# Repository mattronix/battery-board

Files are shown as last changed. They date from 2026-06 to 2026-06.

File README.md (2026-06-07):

# PRC‑152A Repro — Battery / Radio Interface Boards

KiCad hardware project for the **battery-to-radio interface** of an AN/PRC‑152(A)
reproduction radio. It contains two small PCBs that mate through spring‑loaded
**pogo‑pin contacts**, plus a shared custom KiCad **footprint library** for those
mechanical contacts.

> All boards are designed in **KiCad 10** and built for fabrication/assembly at
> JLCPCB (Fabrication Toolkit export, JLCPCB BOM).

---

## Repository layout

```
battery-board/
├── Battery Top/                      # Board that sits on the battery
│   ├── Battery Top/                  # KiCad project (.kicad_pro/.kicad_sch/.kicad_pcb)
│   │   └── production/               # Gerbers/BOM/positions for JLCPCB
│   └── BOM/                          # JLCPCB BOM spreadsheet
├── Radio Bottom/                     # Board that sits on the radio body
│   └── Battery Bottom/               # KiCad project (folder name differs from board name)
├── Kicad Footprint Libaries/
│   └── Radio Library.pretty/         # ← the shared custom footprint library
└── README.md
```

> Note: a couple of folder names are inconsistent with the board names
> (`Radio Bottom/Battery Bottom/...`). The board you load is the `.kicad_pro`
> inside each, not the folder name.

---

## The two boards

### Battery Top
The interface board on the **battery** side. Carries power up to the radio and
exposes the data line.

| Ref | Part | Footprint | Purpose |
|-----|---|---|---|
| J1 | JST XH 3‑pin vertical | `Connector_JST:...B3B-XH-A` | Battery power/data harness |
| J2, J3 | Pogo pin | `Radio Library:Pogo Battery 7MM` | VBAT+ contacts to radio |
| J5 | Pogo pin | `Radio Library:Pogo Battery 7MM` | DATA contact to radio |
| J4, J6 | Bolt pad | `Radio Library:Bolt Pad 4.25` | GND / M4 mounting bolt |
| F1 | 1206 fuse | `Fuse:Fuse_1206_3216Metric` | VBAT+ protection |

### Radio Bottom
The interface board on the **radio** side. It does battery current/power
monitoring and switches the load.

| Ref | Part | Footprint | Purpose |
|-----|---|---|---|
| U1 | **INA226** power monitor | `Package_SO:MSOP-10_3x3mm` | I²C voltage/current/power sense |
| R1 | 5 mΩ shunt | `Resistor_SMD:R_2512_6332Metric` | Current‑sense resistor for U1 |
| Q1 | AOD403 / FQP27P06 P‑MOSFET | `Package_TO_SOT_SMD:TO-252-2` | Load switch / reverse protection |
| D1 | Zener | `Diode_SMD:D_SOD-123` | Gate / rail clamp |
| C1 | 0.1 µF 0603 | `Capacitor_SMD:C_0603` | Decoupling |
| R4 | 100 kΩ 0603 | `Resistor_SMD:R_0603` | Bias/pull |
| J1 | JST XH 6‑pin vertical | `Connector_JST:...B6B-XH-A` | Harness to radio |
| J2,J3 | Pogo pin | `Radio Library:Pogo Radio Bottom 6MM` | Power/data contacts from battery |
| J4,J6 | Bolt pad | `Radio Library:Bolt Pad 4.25` | GND / mounting bolt |

The two boards face each other: the **Pogo Battery 7MM** contacts on *Battery Top*
press onto the **Pogo Radio Bottom 6MM** contacts on *Radio Bottom*, carrying
VBAT+, GND and DATA across the mechanical joint. The INA226 + 5 mΩ shunt measure
battery current/voltage and report over the data line.

---

## Additional parts required (beyond the BOMs)

The electronic BOM spreadsheets (`*/BOM/*.xls`) cover the parts placed by JLCPCB.
You also need the following mechanical / assembly parts to build a working unit:

| Part | Spec / Source | Used on |
|---|---|---|
| Battery | 1× — [AliExpress](https://www.aliexpress.com/item/1005009778488275.html) | Battery Top |
| O‑ring | 13.9 × 1.8 mm | Assembly seal |
| Stainless‑steel printed part | Metal (stainless) 3D print | Mechanical |
| Battery tabs | — | Battery Top |
| Pogo pin — Radio side, 6 mm height | [AliExpress](https://www.aliexpress.com/item/1005006095992803.html) | Radio Bottom (`Pogo Radio Bottom 6MM`) |
| Pogo pin — Battery side, 7 mm height | [AliExpress](https://www.aliexpress.com/item/32862727404.html) | Battery Top (`Pogo Battery 7MM`) |

---

## The custom footprint library (`Radio Library`)

`Kicad Footprint Libaries/Radio Library.pretty/` is a standard KiCad `.pretty`
footprint library — a folder of `.kicad_mod` files, one per footprint. It holds
the **non‑standard mechanical contacts** that aren't in KiCad's stock libraries.

| Footprint | Pad | Drill | Pad Ø | Used for |
|---|-----|---|---|---|
| **Pogo Battery 7MM** | 1× THT circle | 1.6 mm | 2.5 mm | Pogo pin pressed from the battery side |
| **Pogo Radio Bottom 6MM** | 1× THT circle | 0.9 mm | 2.5 mm | Mating pogo target on the radio side |
| **Bolt Pad 4.25** | 1× THT circle | 4.3 mm | 7 mm | M4 mounting bolt + GND pad |

Each is a single through‑hole pad — these are mechanical/contact features rather
than multi‑pin parts, so the drill size is chosen to fit the specific pogo pin or
bolt.

> `*.kicad_mod.rsls` and `Untitled*` files in the library folder are editor
> scratch/temp artifacts and are not real footprints.

### How the boards find the library

Each project's `fp-lib-table` registers the library under the nickname
**`Radio Library`** via an **absolute path**:

```
(lib (name "Radio Library") (type "KiCad")
     (uri "/Users/.../PCB Design/Kicad Footprint Libaries/Radio Library.pretty"))
```

Footprints are then referenced as `Radio Library:<name>` (e.g.
`Radio Library:Pogo Battery 7MM`) in the PCBs.

⚠️ **The path is hard‑coded and absolute.** On another machine (or if you move the
repo) KiCad won't find the library and the custom footprints will show as
unresolved. Fix it one of two ways:

1. **Per project** — open *Preferences → Manage Footprint Libraries → Project*
   and re‑point the `Radio Library` row at this repo's
   `Kicad Footprint Libaries/Radio Library.pretty`, **or**
2. **Use a path variable** — define `KIPRJMOD`‑relative or a custom
   `${RADIO_LIB}` environment variable and edit each `fp-lib-table` to use it,
   so the project is portable.

---

## Working with the project

### Open in KiCad
Open the `.kicad_pro` inside `Battery Top/Battery Top/` or
`Radio Bottom/Battery Bottom/`. If footprints are unresolved, fix the
`Radio Library` path as described above.

### Re‑generate fabrication output
Each project has a `production/` folder (gerbers zip, `bom.csv`,
`positions.csv`, `designators.csv`) produced by the **Fabrication Toolkit**
plugin (settings in `fabrication-toolkit-options.json`). Re‑run the plugin after
PCB changes to refresh these, then upload the zip + BOM to JLCPCB.

---

## Contributing

Improvements are welcome. Open an issue for anything non‑trivial, keep pull
requests focused on one change, and re‑export the `production/` output if you
touch a PCB. See [`CONTRIBUTING.md`](CONTRIBUTING.md) for the full workflow and
guidelines.

## License

This project is licensed under the **CERN Open Hardware Licence Version 2 –
Weakly Reciprocal (CERN‑OHL‑W v2)** — see [`LICENSE`](LICENSE).

You are free to use, study, modify, share and manufacture these designs. Because
the licence is *weakly reciprocal*, if you **distribute modified versions** of
these boards you must make your modified design (source) files **available under
the same licence**. The boards may be incorporated into a larger product without
that product as a whole having to be open.

`SPDX-License-Identifier: CERN-OHL-W-2.0`

## Notes

- `.gitignore` only excludes `.DS_Store`. KiCad lock files (`~*.lck`), `.history/`
  editor backups, and `production/` outputs are currently committed — consider
  ignoring the first two.
- Footprint files carry KiCad 10 (`version 20260206`, `generator_version 10.0`);
  open with KiCad 10 or newer to avoid format warnings.

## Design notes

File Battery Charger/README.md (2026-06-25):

# Battery Charger

Off‑the‑shelf charger used to charge the battery pack for the PRC‑152A
reproduction. This is **not a board designed in this repo** — it is a purchased
module. The `Fusion/` folder holds the mechanical model for fitting/mounting it.

## BOM

| Part | Spec | Source |
|---|---|---|
| Lithium battery charger module | **3S, 2 A** | [AliExpress](https://nl.aliexpress.com/item/1005006823992898.html) — select the **3S 2 A** variant |

> ⚠️ Order the **3S 2 A** variant specifically. The listing offers multiple
> cell‑count (S) and current (A) options; only the 3S 2 A part matches this pack.

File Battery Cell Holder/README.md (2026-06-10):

# Battery Cell Holder

The cell pack of the PRC‑152A reproduction. Two stacked PCBs sandwich the
cylindrical cells: one board carries the spring contacts at each cell end, and
the pack feeds the *Battery Top* interface board. The custom **spring‑contact**
footprint library used by both boards lives here too.

## Layout

```
Battery Cell Holder/
├── Battery Cell Holder Top PCB/
│   └── Kicad/                 # KiCad 10 project — open Battery Cell Holder Top PCB.kicad_pro
├── Battery Cell Holder Bottom PCB/
│   └── Kicad/                 # KiCad 10 project — open Battery Cell Bottom PCB.kicad_pro
└── BatterySpringContact-kicad/   # shared custom symbol + footprint library (see its own README)
```

> Note: the bottom board's project file is named `Battery Cell Bottom PCB.*`
> while its folder is `Battery Cell Holder Bottom PCB/` — open the `.kicad_pro`,
> not the folder name.

## The two boards

Each board carries six battery spring contacts (`BT1`–`BT6`) plus solder‑wire
test points (`TP1`–`TP4`). The top and bottom boards face the opposite ends of
the cells so the springs press axially onto the cell terminals.

| Ref | Part | Footprint | Purpose |
|-----|---|---|---|
| BT1–BT6 | Battery spring contact | `BatterySpringContact:Keystone_5222_SpringContact_THM` | Per‑cell end contacts |
| BT | Battery spring contact (plate) | `BatterySpringContact:BatteryContact_uxcell_Plate_TabSolder_18650` | Plate‑style contact variant |
| TP1–TP4 | Test point | `Connector_Wire:SolderWire-1.5sqmm_1x01_D1.7mm_OD3.9mm` | Wire solder / probe points |

These are generic mechanical contacts with **no LCSC part number**, so JLCPCB's
pick‑and‑place can't assemble them — the board is fabricated with the correct
land and you **hand‑solder** the contacts afterward.

## Footprint library

`BatterySpringContact-kicad/` is a standard KiCad symbol + `.pretty` footprint
library for the stamped 18650/AA spring contacts (coil‑spring negative end,
conical‑button positive end, plus a 7 mm conical PCB spring). It carries its own
detailed README — including footprint dimensions to measure, mounting notes, and
the 3D‑model setup. **Read [`BatterySpringContact-kicad/README.md`](BatterySpringContact-kicad/README.md) before editing the footprints.**

⚠️ The 7 mm conical PCB spring uses 0.3 mm wire — low current capacity. Fine for
sense/monitor paths; do **not** route high pack‑discharge current through it.

## Working with it

1. Open the `.kicad_pro` in **KiCad 10** or newer (one project per board).
2. If the `Battery_Spring_Contact` symbol or its footprints show as unresolved,
   register the `BatterySpringContact` symbol/footprint libraries under that
   nickname — see [`BatterySpringContact-kicad/README.md`](BatterySpringContact-kicad/README.md).
3. The footprint references the STEP model via `${KIPRJMOD}`, so copy the
   `.step`/`.wrl` next to the `.kicad_pcb` (or re‑point the 3D‑model path) for
   the 3D viewer.

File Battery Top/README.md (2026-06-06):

# Battery Top

Interface board on the **battery** side of the PRC‑152A reproduction. It carries
power up from the battery to the radio and exposes the data line, mating to
*Radio Bottom* through spring‑loaded pogo‑pin contacts.

## Layout

```
Battery Top/
├── Kicad/                 # KiCad 10 project — open Battery Top.kicad_pro here
│   ├── Battery Top.kicad_pro / .kicad_sch / .kicad_pcb / .kicad_dru
│   ├── fp-lib-table       # registers the shared "Radio Library" footprint lib
│   ├── fabrication-toolkit-options.json
│   └── production/        # JLCPCB output (gerbers zip, BOM, positions) — git-ignored
└── BOM/
    └── JLPCB BOM v1.xls   # JLCPCB BOM spreadsheet
```

## Key components

| Ref | Part | Footprint | Purpose |
|-----|---|---|---|
| J1 | JST XH 3‑pin vertical | `Connector_JST:...B3B-XH-A` | Battery power/data harness |
| J2, J3 | Pogo pin | `Radio Library:Pogo Battery 7MM` | VBAT+ contacts to radio |
| J5 | Pogo pin | `Radio Library:Pogo Battery 7MM` | DATA contact to radio |
| J4, J6 | Bolt pad | `Radio Library:Bolt Pad 4.25` | GND / M4 mounting bolt |
| F1 | 1206 fuse | `Fuse:Fuse_1206_3216Metric` | VBAT+ protection |

The **Pogo Battery 7MM** contacts here press onto the **Pogo Radio Bottom 6MM**
targets on *Radio Bottom*, carrying VBAT+, GND and DATA across the joint.

## Working with it

1. Open `Kicad/Battery Top.kicad_pro` in **KiCad 10** or newer.
2. If the custom pogo/bolt footprints show as unresolved, re‑point the
   `Radio Library` entry — see [`../Kicad Footprint Libaries/README.md`](../Kicad%20Footprint%20Libaries/README.md).
3. After PCB changes, re‑run the **Fabrication Toolkit** plugin to refresh
   `production/`, then upload the zip + BOM to JLCPCB.

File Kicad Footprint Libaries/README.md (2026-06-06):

# Kicad Footprint Libaries

Shared custom KiCad footprint library for the PRC‑152A interface boards. Both
*Battery Top* and *Radio Bottom* reference it under the nickname **`Radio Library`**.

## Layout

```
Kicad Footprint Libaries/
└── Radio Library.pretty/   # standard KiCad .pretty library (one .kicad_mod per footprint)
```

A `.pretty` folder is just a directory of `.kicad_mod` files — KiCad treats the
folder itself as one library.

## Footprints

These are the **non‑standard mechanical contacts** that aren't in KiCad's stock
libraries. Each is a single through‑hole pad — a mechanical/contact feature, not
a multi‑pin part — sized to fit a specific pogo pin or bolt.

| Footprint | Pad | Drill | Pad Ø | Used for |
|---|-----|---|---|---|
| **Pogo Battery 7MM** | 1× THT circle | 1.6 mm | 2.5 mm | Pogo pin pressed from the battery side |
| **Pogo Radio Bottom 6MM** | 1× THT circle | 0.9 mm | 2.5 mm | Mating pogo target on the radio side |
| **Bolt Pad 4.25** | 1× THT circle | 4.3 mm | 7 mm | M4 mounting bolt + GND pad |

> `*.kicad_mod.rsls` and `Untitled*` files are editor scratch/temp artifacts, not
> real footprints (they are git‑ignored).

## How projects find the library

Each project's `fp-lib-table` registers this library under the nickname
**`Radio Library`** via an **absolute path**:

```
(lib (name "Radio Library") (type "KiCad")
     (uri "/Users/.../Kicad Footprint Libaries/Radio Library.pretty"))
```

Footprints are then referenced as `Radio Library:<name>` (e.g.
`Radio Library:Pogo Battery 7MM`) in the PCBs.

⚠️ **The path is hard‑coded and absolute.** On another machine — or if the repo
moves — KiCad won't find the library and the custom footprints show as unresolved.
Fix it one of two ways:

1. **Per project** — *Preferences → Manage Footprint Libraries → Project* and
   re‑point the `Radio Library` row at this repo's `Radio Library.pretty`, **or**
2. **Use a path variable** — define a custom `${RADIO_LIB}` environment variable
   and edit each `fp-lib-table` to use it, so the projects stay portable.

Footprints carry the KiCad 10 format (`version 20260206`, `generator_version 10.0`);
open with KiCad 10 or newer to avoid format warnings.

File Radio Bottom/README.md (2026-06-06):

# Radio Bottom

Interface board on the **radio** side of the PRC‑152A reproduction. It does
battery voltage/current/power monitoring (INA226 + shunt) and switches the load,
mating to *Battery Top* through spring‑loaded pogo‑pin contacts.

## Layout

```
Radio Bottom/
├── Kicad/                  # KiCad 10 project — open Radio Bottom.kicad_pro here
│   ├── Radio Bottom.kicad_pro / .kicad_sch / .kicad_pcb / .kicad_dru
│   ├── fp-lib-table        # registers the shared "Radio Library" footprint lib
│   └── fabrication-toolkit-options.json
└── BOM/
    └── Radio Bottom BOM V1.xls   # JLCPCB BOM spreadsheet
```

## Key components

| Ref | Part | Footprint | Purpose |
|-----|---|---|---|
| U1 | **INA226** power monitor | `Package_SO:MSOP-10_3x3mm` | I²C voltage/current/power sense |
| R1 | 5 mΩ shunt | `Resistor_SMD:R_2512_6332Metric` | Current‑sense resistor for U1 |
| Q1 | AOD403 / FQP27P06 P‑MOSFET | `Package_TO_SOT_SMD:TO-252-2` | Load switch / reverse protection |
| D1 | Zener | `Diode_SMD:D_SOD-123` | Gate / rail clamp |
| C1 | 0.1 µF 0603 | `Capacitor_SMD:C_0603` | Decoupling |
| R4 | 100 kΩ 0603 | `Resistor_SMD:R_0603` | Bias/pull |
| J1 | JST XH 6‑pin vertical | `Connector_JST:...B6B-XH-A` | Harness to radio |
| J2, J3 | Pogo pin | `Radio Library:Pogo Radio Bottom 6MM` | Power/data contacts from battery |
| J4, J6 | Bolt pad | `Radio Library:Bolt Pad 4.25` | GND / mounting bolt |

The **Pogo Radio Bottom 6MM** targets here receive the **Pogo Battery 7MM**
contacts from *Battery Top*. The INA226 + 5 mΩ shunt measure battery
current/voltage and report over the data line.

## Working with it

1. Open `Kicad/Radio Bottom.kicad_pro` in **KiCad 10** or newer.
2. If the custom pogo/bolt footprints show as unresolved, re‑point the
   `Radio Library` entry — see [`../Kicad Footprint Libaries/README.md`](../Kicad%20Footprint%20Libaries/README.md).
3. After PCB changes, re‑run the **Fabrication Toolkit** plugin to refresh the
   fabrication output, then upload the zip + BOM to JLCPCB.

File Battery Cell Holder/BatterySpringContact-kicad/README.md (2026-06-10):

# Battery Contact — KiCad library (uxcell plate-style spring/button)

KiCad symbol + footprints for the uxcell-style stamped 18650/AA battery contact set
(flat plate, solder tab with end hole; coil spring = negative end, conical button =
positive end). One footprint serves BOTH ends — they mount identically; only the
cell-side feature differs.

## Contents
- `BatterySpringContact.kicad_sym` — symbol `Battery_Spring_Contact` (1 pin, passive)
- `BatterySpringContact.pretty/`
  - `BatteryContact_uxcell_Plate_TabSolder_18650.kicad_mod`  ← use this for your part
  - `Keystone_5222_SpringContact_THM.kicad_mod`              ← coil-spring alt (legacy)

## JLCPCB reality (read this)
This is a generic mechanical contact with NO LCSC part number, so JLCPCB's pick-and-place
CANNOT assemble it. JLCPCB will fabricate the board with the correct land; you HAND-SOLDER
the contacts afterward. Want JLCPCB to actually place a spring during assembly? You must
switch to an LCSC-catalogued SMD battery clip instead.

## How the footprint mounts
- Lay the metal tab FLAT onto the SMD pad and solder it (iron or paste+hotplate).
- The plated through-hole at the tab end is a solder/wire anchor.
- The plate + spring/button stands UP off the board toward the cell.
- Both the pad and the hole are tied to net "1" (single contact = one node).

## Footprint dimensions — NOMINAL, MEASURE TO CONFIRM
Built for the ~16 mm 18650 plate variant. Check these 5 numbers with calipers and edit
the `.kicad_mod` (values in mm):
1. Plate width (across) — sets fab/silk/courtyard circle. Nominal 16 (radius 8).
2. Tab length — sets SMD pad X (`size 9 6`) and pad center (`at 10.5 0`). Nominal ~9.
3. Tab width — sets SMD pad Y. Nominal 6.
4. Tab-end hole diameter — sets drill (`drill 1.8`). Nominal 1.8.
5. Plate-edge → hole-center distance — sets PTH `at 13 0`. Nominal 13.

Common size families if unsure: AA ≈ 12–13 mm plate; 18650 ≈ 16×16 or 18.5×16 mm.

## Install (KiCad 8)
1. Symbol: Preferences → Manage Symbol Libraries → add `BatterySpringContact.kicad_sym`
   (nickname `BatterySpringContact`).
2. Footprint: Preferences → Manage Footprint Libraries → add the `BatterySpringContact.pretty`
   folder under the SAME nickname so the symbol's default-footprint link resolves.
3. Place `Battery_Spring_Contact` once per cell end; assign +/− nets as needed.

## Mechanical (your 3D-printed shell)
- Capture the plate in the printed shell; don't rely on the solder joint for retention,
  especially under recoil/vibration (milsim use).
- Size the shell around the spring's COMPRESSED height so flat-top and protected cells
  both seat under contact pressure.

## RECOMMENDED footprint: BatterySpringContact_ConicalPCB_7mm
Conical PCB coil-spring contact (the 7 mm one). Verified dimensions:
- base coil OD 7 mm  -> 7.5 mm circular solder pad
- top coil OD 5 mm   -> what the cell end presses on
- free height 7 mm, wire 0.3 mm
Mount: solder base coil flat to the round pad; cell compresses the top axially.
This is the symbol's default footprint now.
WARNING: 0.3 mm wire is thin -> low current capacity. Great for sense/monitor or
low-current paths; do NOT route high pack-discharge current through it. Hand-solder
with flux (nickel-plated steel wets poorly); NOT JLCPCB pick-and-place.

## 3D model (STEP + WRL)
Files `BatterySpringContact_ConicalPCB_7mm.step` (66 KB, true mm) and `.wrl` (render).
The footprint already references the STEP via:
  (model "${KIPRJMOD}/BatterySpringContact_ConicalPCB_7mm.step" ...)
So the SIMPLEST setup: copy the .step (and .wrl) file into your KiCad PROJECT folder
(next to your .kicad_pcb) and ${KIPRJMOD} resolves automatically.

If you keep the models inside the .pretty folder instead, re-point the path:
  PCB editor -> double-click the footprint -> 3D Models tab -> remove the entry ->
  Add -> browse to the .step file. KiCad writes the correct absolute path for you.

Model is authored base-at-origin, +Z up (sits on top copper, spring points at the cell),
so offset/rotate are zero and scale is 1. KiCad 8's 3D viewer renders STEP directly.

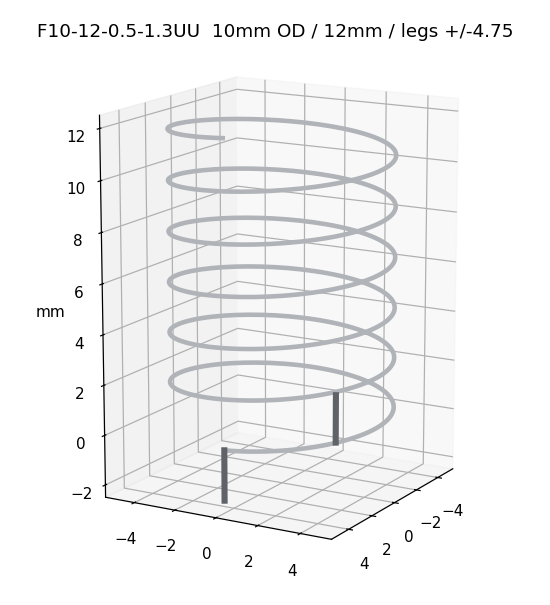
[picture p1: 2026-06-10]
Battery Cell Holder/BatterySpringContact-kicad/files/f10_preview.png

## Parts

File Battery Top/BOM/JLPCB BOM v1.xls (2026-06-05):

Comment | Designator | Footprint | JLCPCB Part # | Qty | Ext.Price($)
FUSE_VBAT+_1 | F1 | 1206 | C883162 | 14 | 1.19
JST_PWR_CON | J1 | JST_XH_B3B-XH-A_1x03_P2.50mm_Vertical | C144394 | 11 | 0.60

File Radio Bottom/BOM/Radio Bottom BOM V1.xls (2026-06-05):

Comment | Designator | Footprint | JLCPCB Part # | Qty | Ext.Price($)
5mΩ | R1 | 2512 | C46634460 | 7 | 0.46
Conn_01x06_Pin | J1 | JST_XH_B6B-XH-A_1x06_P2.50mm_Vertical | C144397 | 5 | 0.44
D_Zener | D1 | D_SOD-123 | C43491 | 15 | 0.28
INA226 | U1 | MSOP-10_3x3mm_P0.5mm | C49851 | 5 | 4.05
100K | R4 | 0603 | C25803 | 5 | 0.01
AOD403 | Q1 | TO_SOT_SMD:TO-252-2 | C5224305 | 5 | 0.77
0.1μF | C1 | 0603 | C1590 | 20 | 0.10

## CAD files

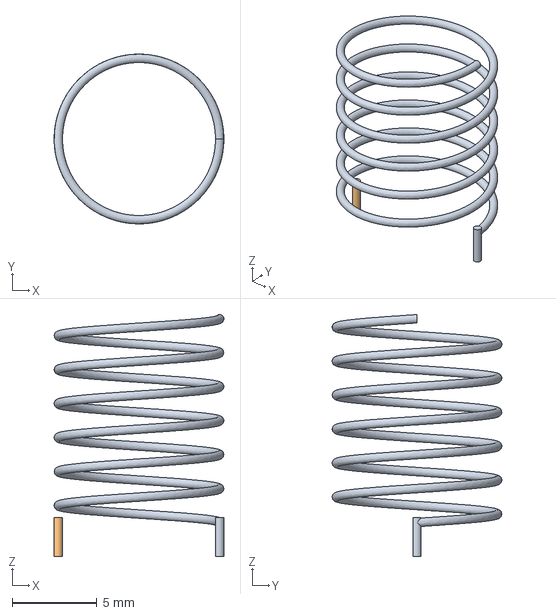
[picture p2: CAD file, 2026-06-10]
Battery Cell Holder/BatterySpringContact-kicad/files/C19724688_F10-12-0.5-1.3UU.step
10.0 x 10.00 x 14.2 mm

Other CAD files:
Battery Cell Holder/Battery Cell Holder Bottom PCB/Fusion/18650 Holder Bottom (Cell Holder PCB).f3z
Battery Cell Holder/Battery Cell Holder Spacer/Fusion/18650 Cell Holder Spacer.f3d
Battery Cell Holder/Battery Cell Holder Top PCB/Fusion/18650 Holder Top (Cell Holder + PCB).f3z
Battery Charger/Fusion/Charger.f3d
Radio Bottom/Fusion/Radio Bottom PCB Compatible.f3d

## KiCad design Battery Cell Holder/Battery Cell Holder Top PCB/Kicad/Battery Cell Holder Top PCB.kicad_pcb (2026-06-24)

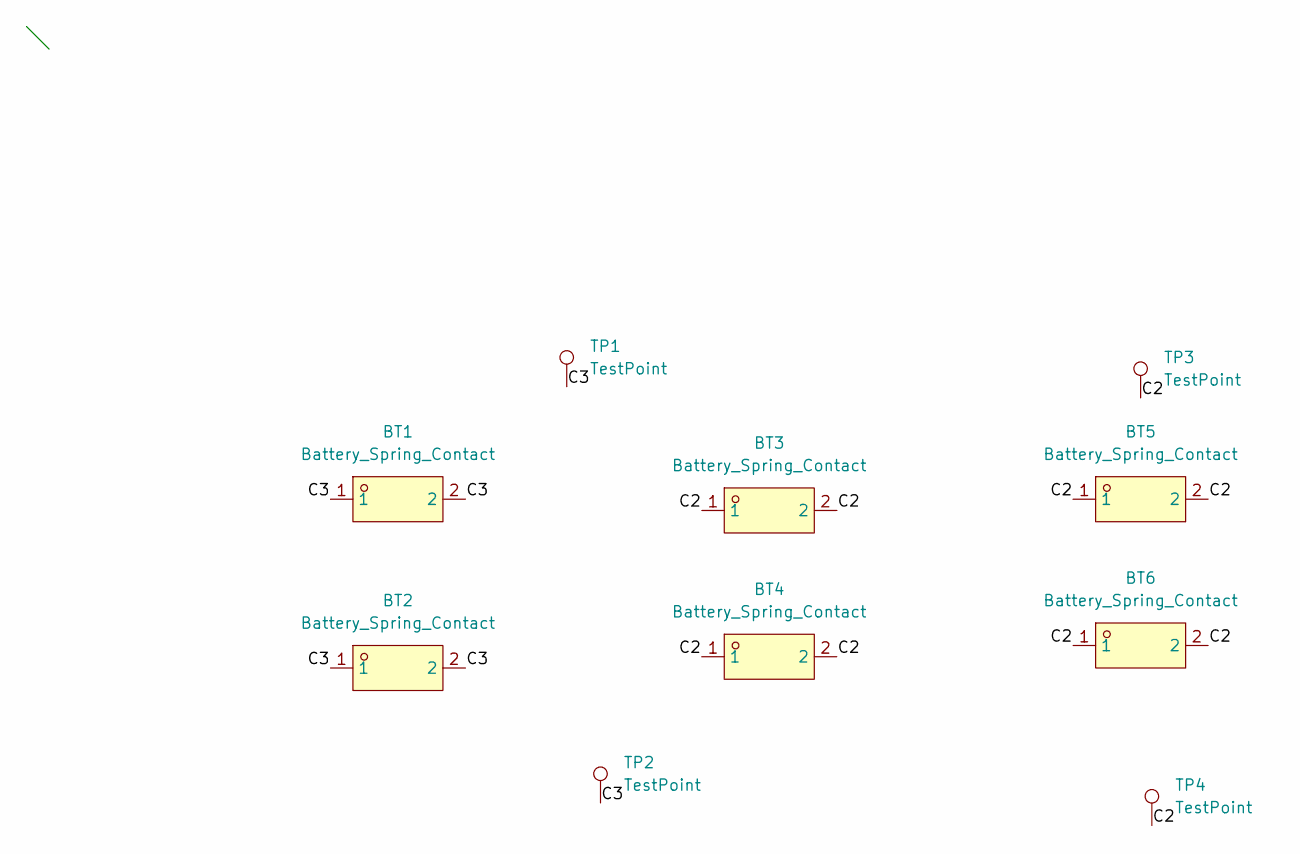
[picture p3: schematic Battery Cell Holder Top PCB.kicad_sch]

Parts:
BT1, BT2, BT3, BT4, BT5, BT6: Battery_Spring_Contact; TH-2_BD10.0_F10-12-0.5-1.3UU-SUS304; MPN F10-12-0.5-1.3UU-sus304; LCSC Part C19724688
TP1, TP2, TP3, TP4: TestPoint; SolderWire-1.5sqmm_1x01_D1.7mm_OD3.9mm

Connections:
/C2: BT3.1, BT3.2, BT4.1, BT4.2, BT5.1, BT5.2, BT6.1, BT6.2, TP3.1 (1_1), TP4.1 (1_1)
/C3: BT1.1, BT1.2, BT2.1, BT2.2, TP1.1 (1_1), TP2.1 (1_1)

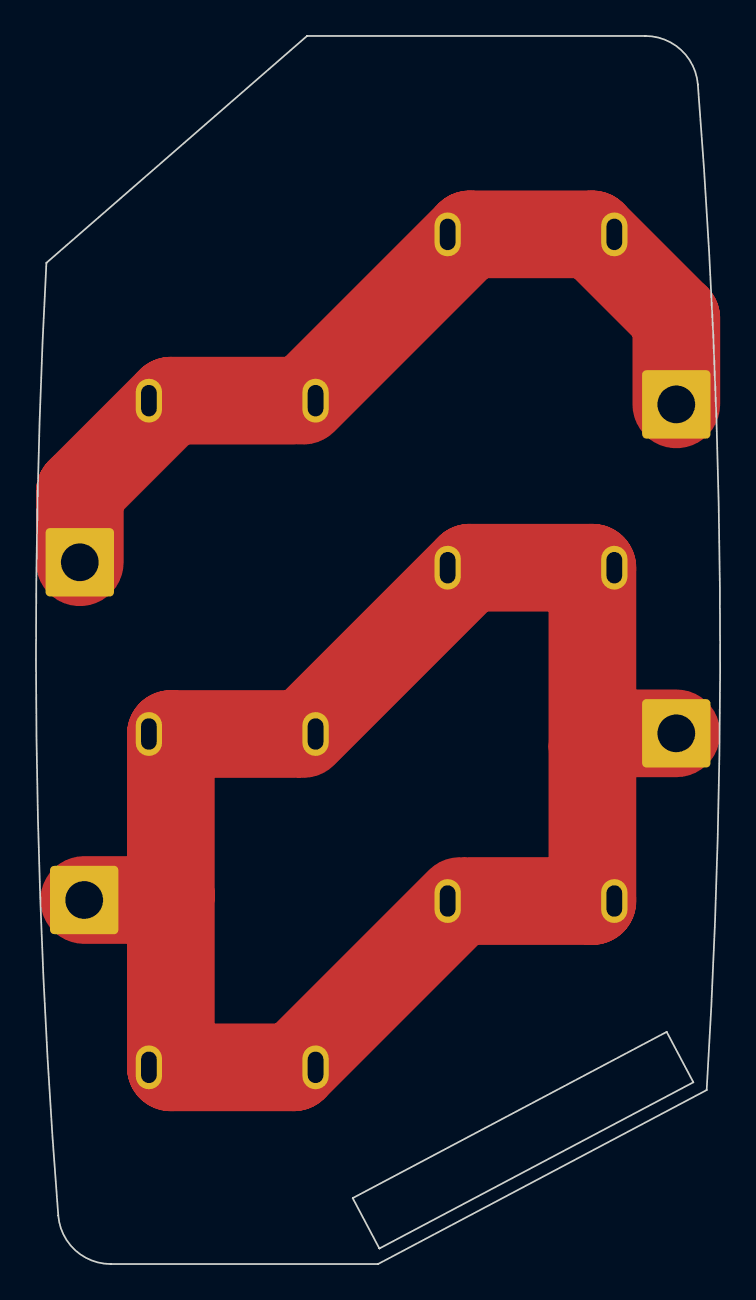
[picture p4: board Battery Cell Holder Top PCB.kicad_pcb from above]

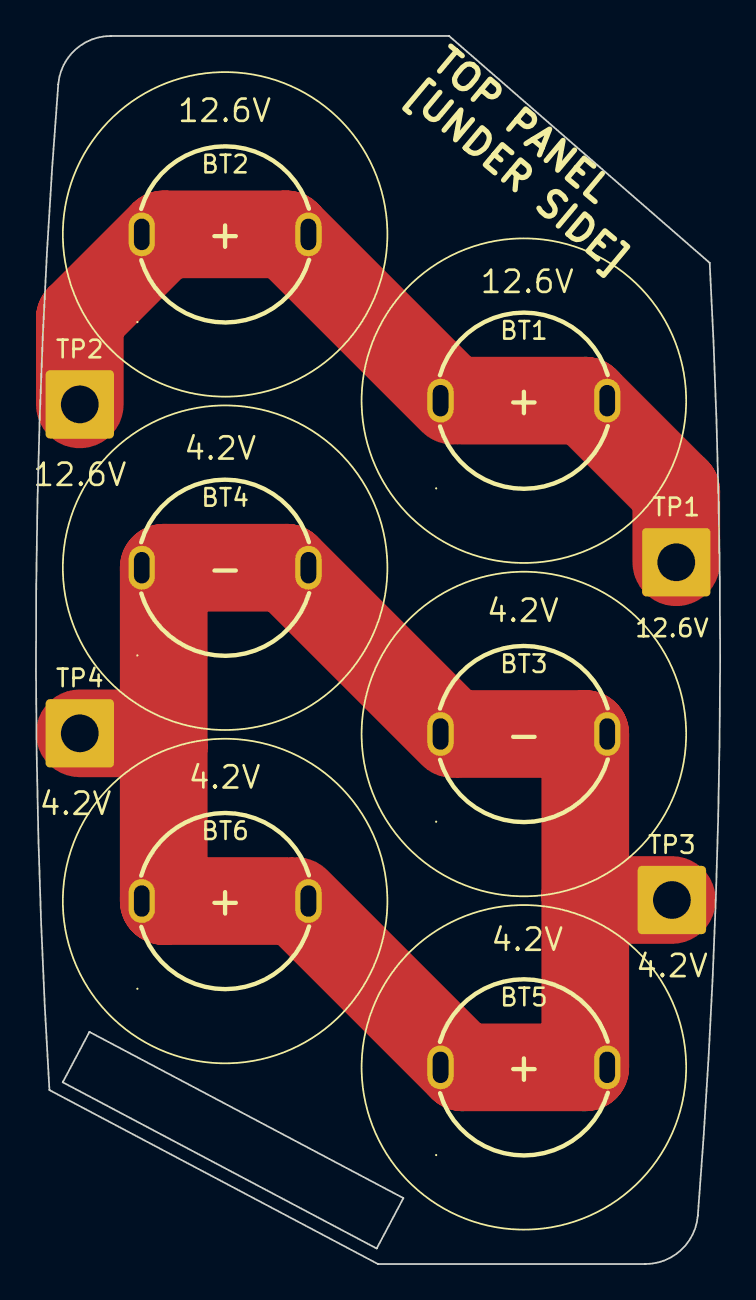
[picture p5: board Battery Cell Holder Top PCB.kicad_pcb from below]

Board: 2 copper layers, 39.0 x 70.0 mm, 10 parts (7 on the bottom side), 2 nets.

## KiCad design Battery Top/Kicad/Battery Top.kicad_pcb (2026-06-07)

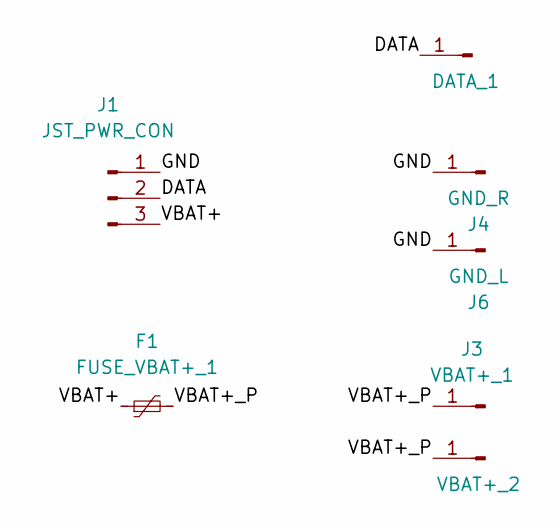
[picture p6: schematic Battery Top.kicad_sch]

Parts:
F1: FUSE_VBAT+_1; R_1812_4532Metric
J1: JST_PWR_CON; JST_XH_B3B-XH-A_1x03_P2.50mm_Vertical
J2: VBAT+_2; Pogo Battery 7MM
J3: VBAT+_1; Pogo Battery 7MM
J4: GND_R; Bolt Pad 4.25
J5: DATA_1; Pogo Battery 7MM
J6: GND_L; Bolt Pad 4.25

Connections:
/DATA: J1.2, J5.1 (Pin_1_1)
/GND: J1.1, J4.1 (Pin_1_1), J6.1 (Pin_1_1)
/VBAT+: F1.1, J1.3
/VBAT+_P: F1.2, J2.1 (Pin_1_1), J3.1 (Pin_1_1)

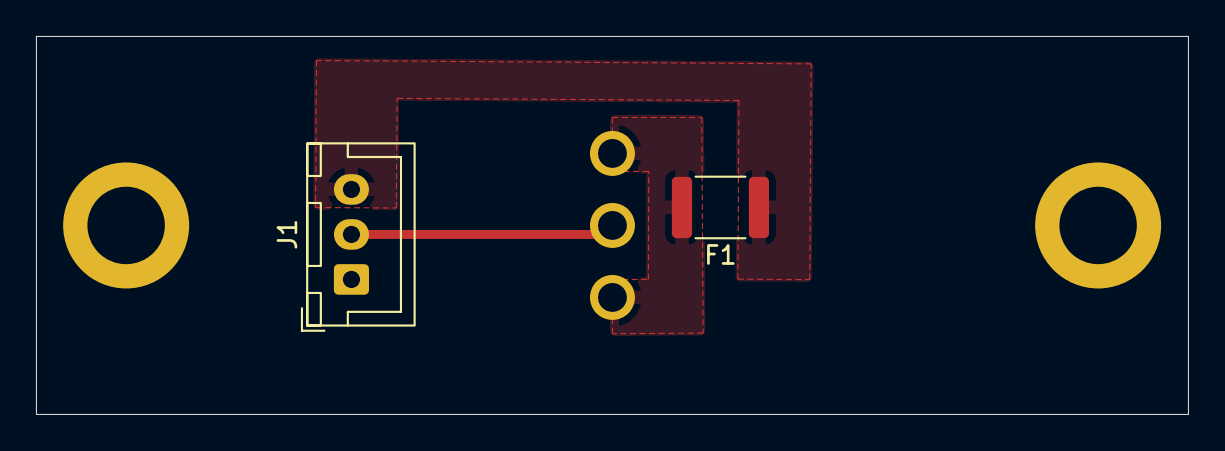
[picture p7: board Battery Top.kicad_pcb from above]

Board: 2 copper layers, 64.0 x 21.0 mm, 7 parts (0 on the bottom side), 4 nets.

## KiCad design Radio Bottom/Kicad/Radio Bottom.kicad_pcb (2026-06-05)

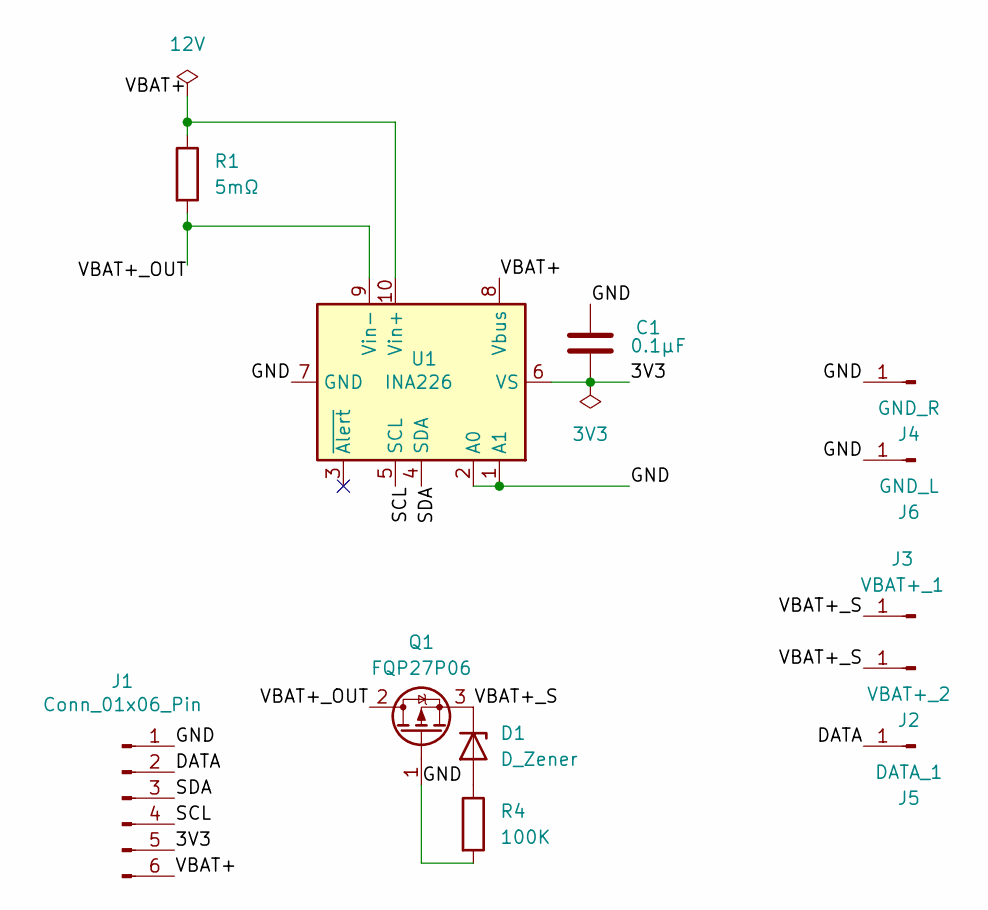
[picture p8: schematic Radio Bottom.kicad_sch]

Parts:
C1: 0.1µF; C_0603_1608Metric
D1: D_Zener; D_SOD-123
J1: Conn_01x06_Pin; JST_XH_B6B-XH-A_1x06_P2.50mm_Vertical
J2: VBAT+_2; Pogo Radio Bottom 6MM
J3: VBAT+_1; Pogo Radio Bottom 6MM
J4: GND_R; Bolt Pad 4.25
J5: DATA_1; Pogo Radio Bottom 6MM
J6: GND_L; Bolt Pad 4.25
Q1: FQP27P06; TO-252-2
R1: 5mΩ; R_2512_6332Metric
R4: 100K; R_0603_1608Metric
U1: INA226; MSOP-10_3x3mm_P0.5mm

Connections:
/3V3: C1.2, J1.5, U1.6 (VS)
/DATA: J1.2, J5.1 (Pin_1_1)
/GND: C1.1, J1.1, J4.1 (Pin_1_1), J6.1 (Pin_1_1), Q1.1 (G), R4.2, U1.1 (A1), U1.2 (A0), U1.7 (GND)
/SCL: J1.4, U1.5 (SCL)
/SDA: J1.3, U1.4 (SDA)
/VBAT+: J1.6, R1.1, U1.8 (Vbus), U1.10 (Vin+)
/VBAT+_OUT: Q1.2 (D), R1.2, U1.9 (Vin-)
/VBAT+_S: D1.1 (K), J2.1 (Pin_1_1), J3.1 (Pin_1_1), Q1.3 (S)
unnamed: D1.2 (A), R4.1

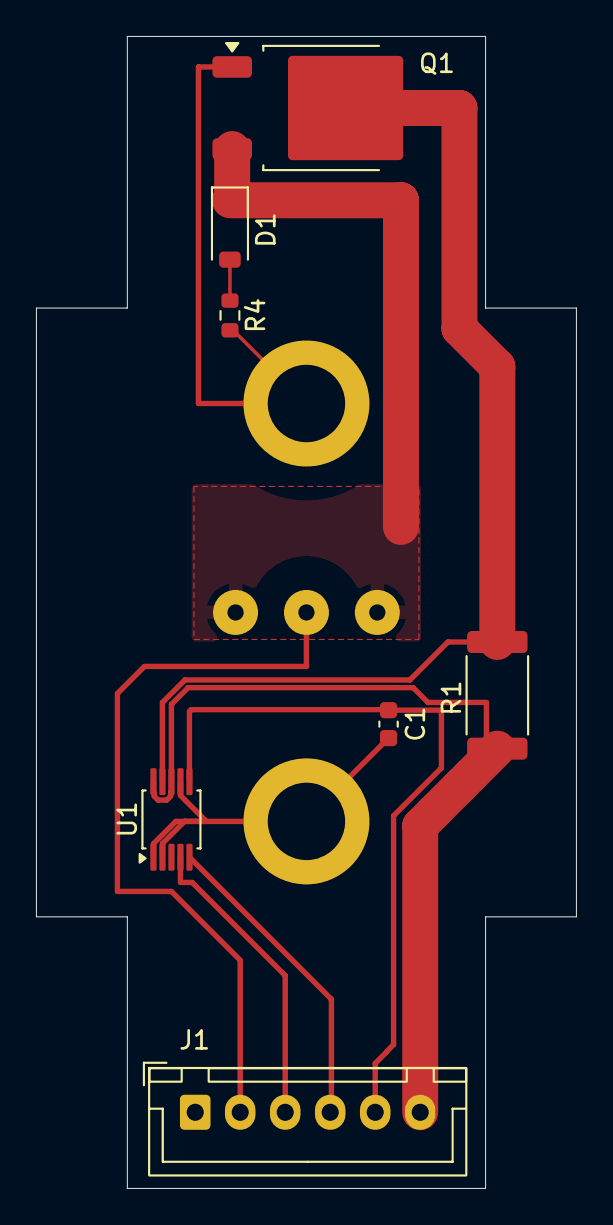
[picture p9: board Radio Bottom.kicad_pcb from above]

Board: 2 copper layers, 30.0 x 64.0 mm, 12 parts (0 on the bottom side), 9 nets.

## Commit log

2026-06-05 useless files
    [Radio Bottom PCB 2d.dxf, Radio Bottom pcb.step, Sketch1.dxf]
2026-06-06 fixed footprint for fuse
    [Battery Top.kicad_pcb, Battery Top.kicad_sch, bom.csv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]
2026-06-06 Clean repo: untrack generated/junk files, add KiCad .gitignore
    - Untrack .history embedded git repos (VS Code Local History)
    - Untrack machine-local *.kicad_prl, scratch *.rsls footprints
    - Untrack fab outputs (*.pos, *.gbrjob) and remove *.lck lock files
    - Add comprehensive KiCad .gitignore (production/, backups, gerbers, etc.)
    [Radio Bottom-job.gbrjob]
2026-06-06 Add per-folder READMEs for top-level board and library folders
2026-06-07 Add required mechanical parts to README; update fuse footprint
    - README: add "Additional parts required (beyond the BOMs)" section
    (battery, O-ring, stainless print, battery tabs, pogo pins)
    - Battery Top: change fuse footprint
    - Remove leftover stray Battery Top.kicad_pro from restructure
    [Battery Top.kicad_sch]
2026-06-10 battery board
    [Battery Cell Bottom PCB.kicad_pcb, Battery Cell Bottom PCB.kicad_sch, Battery Cell Holder Top PCB.kicad_pcb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]
2026-06-10 fixes to boards
    [Battery Cell Bottom PCB.kicad_pcb, Battery Cell Holder Bottom PCB.kicad_pcb, Battery Cell Holder Bottom PCB.kicad_sch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]
2026-06-10 fabrication + 3d model of custom battery holder
    [18650 Holder Bottom (Cell Holder PCB).3mf]
2026-06-10 fusion files for customer board
    [18650 Holder Bottom (Cell Holder PCB).3mf, 18650 Holder Bottom (Cell Holder PCB).f3z, 18650 Holder Top (Cell Holder + PCB).f3z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]
2026-06-11 added full model rendering
    [18650 Cell Holder Spacer.f3d]
2026-06-25 snug fit
    [Radio Bottom PCB Compatible.f3d]
